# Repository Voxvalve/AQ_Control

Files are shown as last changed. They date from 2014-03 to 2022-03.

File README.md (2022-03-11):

==========
AQ_Control
==========

AQ_Control is an Arduino aquarium control system.

THE STORY:
--------------------------
It all started with me wanting something better then just a thermometer in each end og my 100cm long aquarium.
When i figured out how easy that was to do with an arduino i thought why not do more. 
also at this point there was alot of empty port on the Arduino UNO.
Then i figured that i might aswell do the light control with also.
After a while playing around with the date time stuff and having to set the time every time i flashed 
i went on amazon and ordered a DS1307 RCT to solve it(It works great!).
now i have all that sorted and i am currently testing the system.
So far everything seems to be working, Tempratures are read and displayed with great precision,
And lights are turned on/off at the specified time.

PARTS I USED:
--------------------------
1 x Arduino UNO.

2 x DS18B20.

1 x DS1307 RCT.

1 x 4-CH Relay Module.

Alot of pins and headers.

Some flat cable.

Some PCB.

Ferric chloride.

Laser printer with photo paper.

An iron.

Soldering iron

FEATURES FOR LATER
--------------------------
 - Web service for monitoring.
 - Email alert system.
 - Dynamic temprature control.
 - Automatic feeding system.

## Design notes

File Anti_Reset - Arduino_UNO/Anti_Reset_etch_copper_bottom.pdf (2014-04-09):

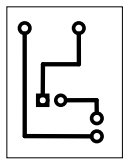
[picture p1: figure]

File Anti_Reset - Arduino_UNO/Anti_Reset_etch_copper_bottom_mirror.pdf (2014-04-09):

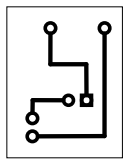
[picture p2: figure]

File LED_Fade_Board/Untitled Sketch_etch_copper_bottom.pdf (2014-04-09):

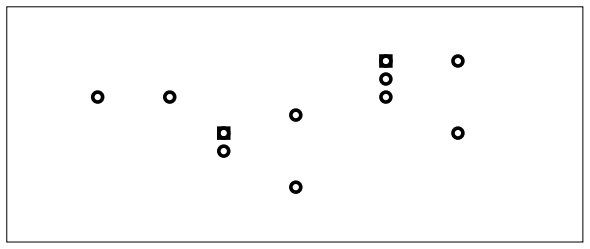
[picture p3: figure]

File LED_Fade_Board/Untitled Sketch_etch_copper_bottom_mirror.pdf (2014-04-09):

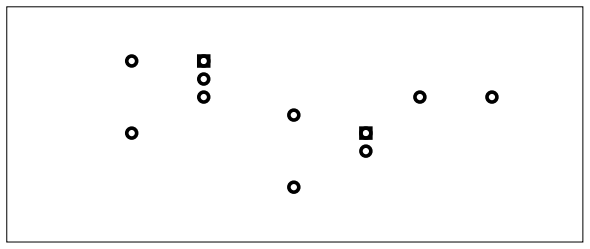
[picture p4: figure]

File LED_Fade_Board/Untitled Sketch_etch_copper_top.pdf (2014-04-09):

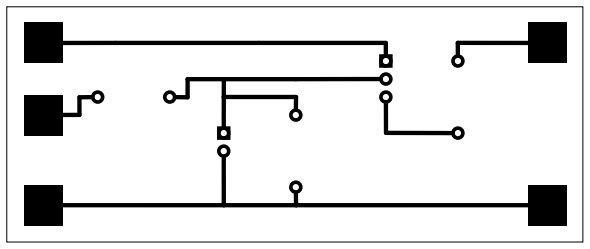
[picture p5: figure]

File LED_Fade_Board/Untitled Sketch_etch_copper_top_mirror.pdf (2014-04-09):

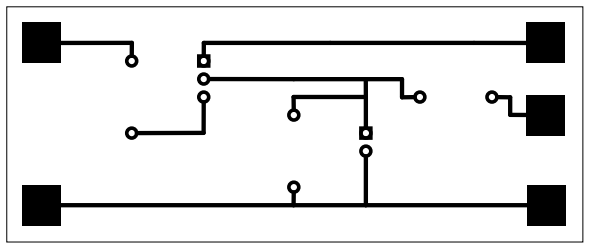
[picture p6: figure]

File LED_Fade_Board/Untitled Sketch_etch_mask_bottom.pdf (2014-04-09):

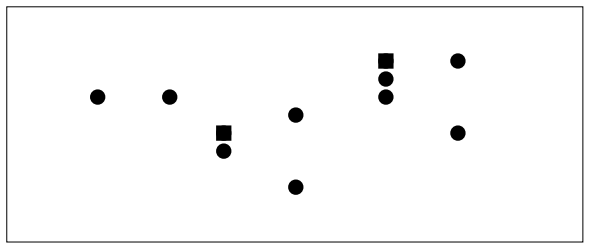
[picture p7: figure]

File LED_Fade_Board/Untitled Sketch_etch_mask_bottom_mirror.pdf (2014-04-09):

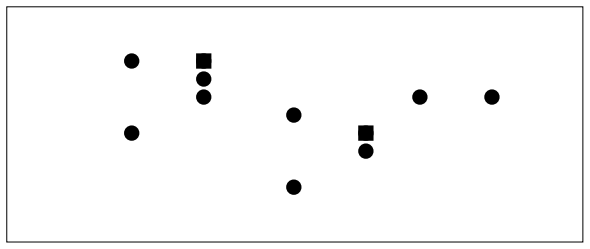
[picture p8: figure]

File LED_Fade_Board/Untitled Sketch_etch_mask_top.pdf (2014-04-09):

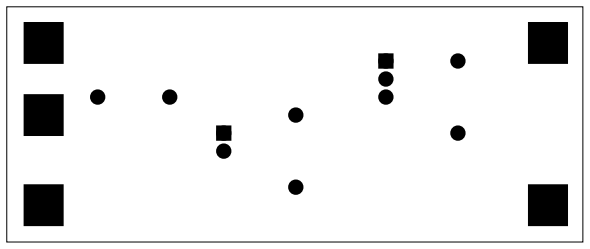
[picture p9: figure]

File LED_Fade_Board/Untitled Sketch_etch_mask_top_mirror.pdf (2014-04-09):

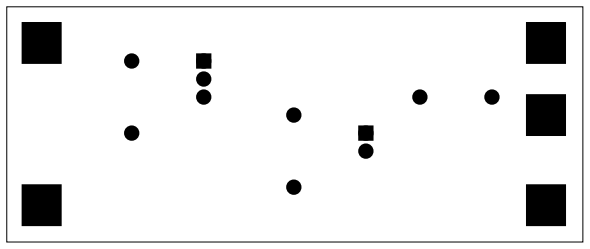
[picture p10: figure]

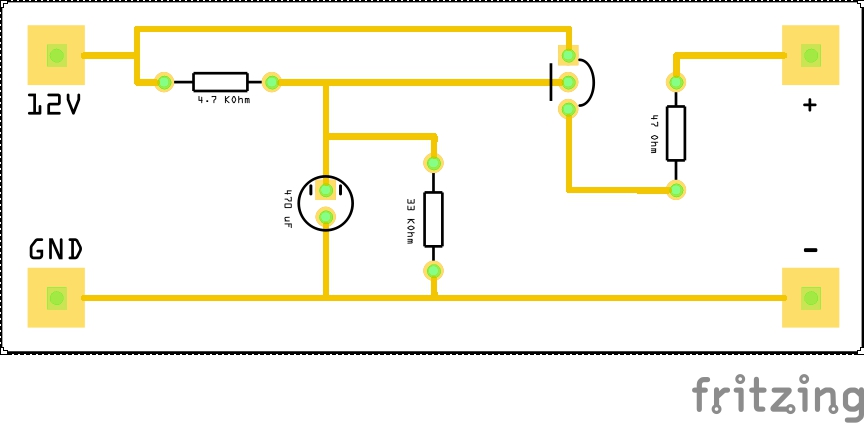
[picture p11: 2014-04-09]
LED_Fade_Board.jpg

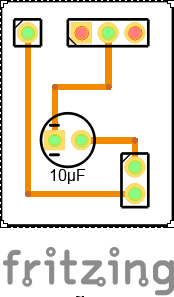
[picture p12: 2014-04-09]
Anti_Reset - Arduino_UNO/Anti_Reset_pcb.png

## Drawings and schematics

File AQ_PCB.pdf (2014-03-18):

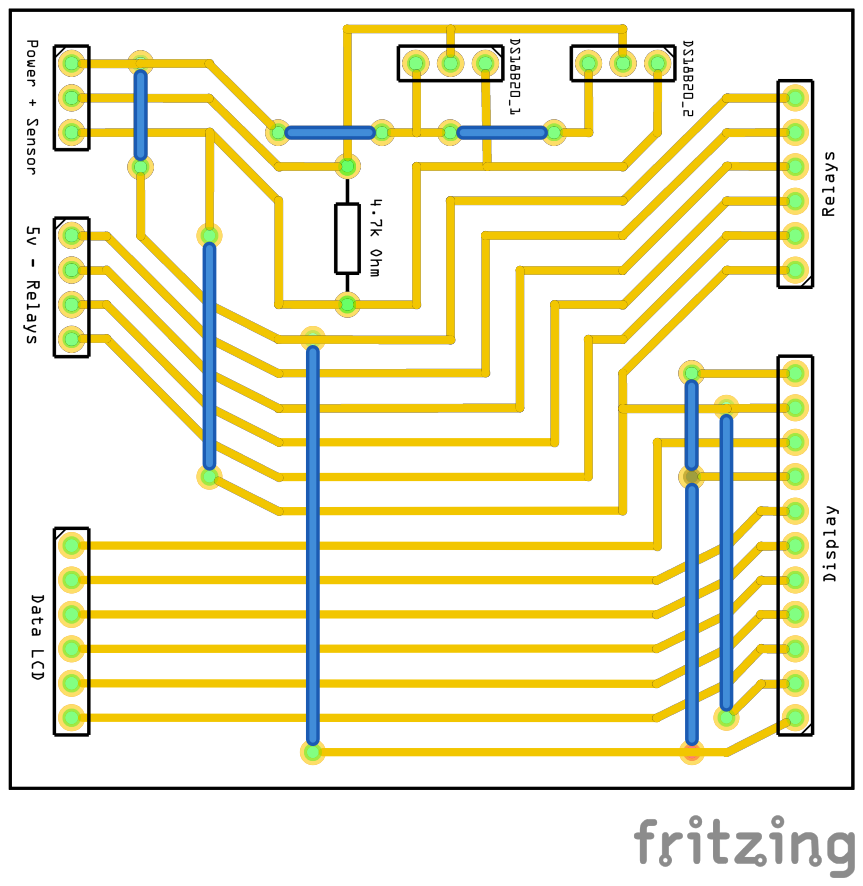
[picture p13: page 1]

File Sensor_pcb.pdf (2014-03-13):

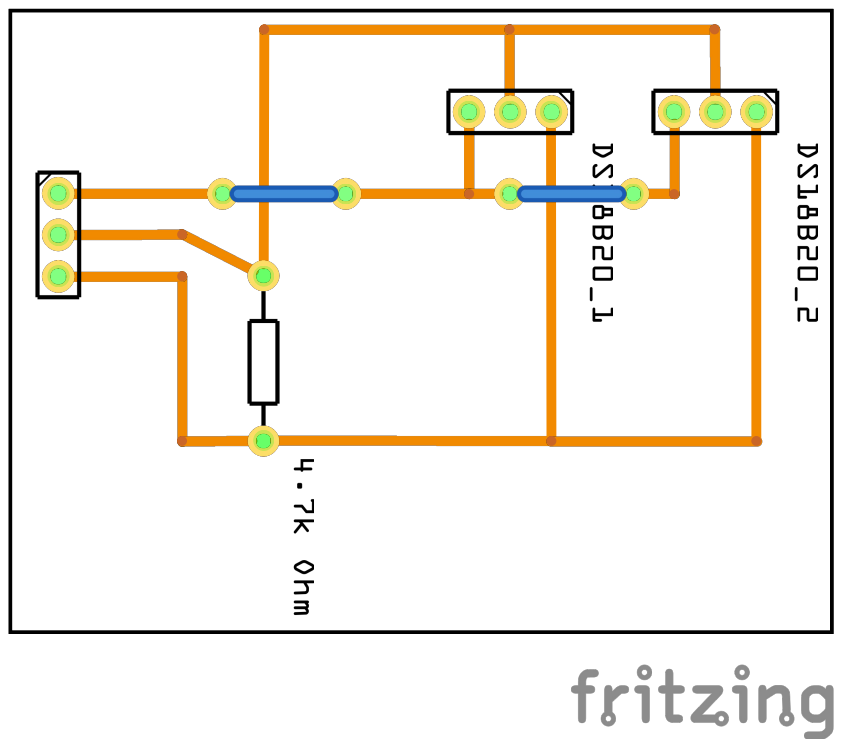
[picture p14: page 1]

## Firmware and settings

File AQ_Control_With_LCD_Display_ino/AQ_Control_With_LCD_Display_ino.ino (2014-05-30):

/*! \Cammand Lists
*      Commands that can used from a serial connection for testing functions.
*
*   1.) Print temprature.
*   2.) Turn on light.
*   3.) Turn off light.
*   4.) Lights Automatic.
*   5.) Print time from RTC.
*/
  
#define DS18S20_ID 0x10
#define DS18B20_ID 0x28
#define DS1307_ADDRESS 0x68
#define ONE_WIRE_BUS_PIN 14
#define RELAY1 8
#define RELAY2 9
#define RELAY3 10
#define RELAY4 11
#include <Wire.h>
#include <OneWire.h>
#include <DallasTemperature.h>
#include <LiquidCrystal.h>


// -- Variables to hold RTC --
int second;                                     
int minute;                                     
int hour;                                       
int weekDay;                                    
int monthDay;                                   
int month;                                      
int year;                                       
// ---------------------------

int intRead;                                    // int to identify command chosen.
int light = 0;                                  // State of lights (0 = Off, 1 = On & 2 = Manual.).
int offTime = 22;                               // Hour of the day to turn off lights.
int onTime = 10;                                // Hour of the day to turn on lights.
float temp;                                     // Holds temprature value of current read.
float temp1;                                    // Holds temprature of sensor1.
float temp2;                                    // Holds temprature of sensor2.
byte zero = 0x00;                               // Workaround for issue #527 in RTC.
LiquidCrystal lcd(2, 3, 4, 5, 6, 7);            // Initialize the library with the numbers of the interface pins.
OneWire oneWire(ONE_WIRE_BUS_PIN);
DallasTemperature sensors(&oneWire);

// Temprature sensor's addresses.
DeviceAddress Probe01 = { 0x28, 0x60, 0xB3, 0xA0, 0x05, 0x00, 0x00, 0x40 }; 
DeviceAddress Probe02 = { 0x28, 0xAD, 0x7A, 0xA0, 0x05, 0x00, 0x00, 0x44 };

/*! \Function to convert time.
*      bcdToDec();
*
*   Convert binary coded decimal 
*   to normal decimal numbers.
*/
byte bcdToDec(byte val)  {

  return ( (val/16*10) + (val%16) );
}

/*! \Function to get time.
*      getDate();
*
*   This gets the time from the DS1307
*/
void getDate() {
  // Reset the register pointer
  Wire.beginTransmission(DS1307_ADDRESS);
  Wire.write(zero);
  Wire.endTransmission();

  Wire.requestFrom(DS1307_ADDRESS, 7);

  second = bcdToDec(Wire.read());
  minute = bcdToDec(Wire.read());
  hour = bcdToDec(Wire.read() & 0b111111);       //24 hour time
  weekDay = bcdToDec(Wire.read());               //0-6 -> sunday - Saturday
  monthDay = bcdToDec(Wire.read());
  month = bcdToDec(Wire.read());
  year = bcdToDec(Wire.read());
}

/*! \Function to print time.
*      printDate();
*
*   Print the date EG 23:59:59
*/
void printDate(){
  
  Serial.print(hour);
  Serial.print(":");
  Serial.print(minute);
  Serial.print(":");
  Serial.println(second);
}

/*! \Function to get temperature.
*      printTemperature();
*
*   This gets the tempreature from
*   the DS18B20's Connected to pin 14
*   and converts it to degrees celsius.
*/
void printTemperature(DeviceAddress deviceAddress) {

   float tempC = sensors.getTempC(deviceAddress);

   if (tempC == -127.00) 
   {
     Serial.print("Error getting temperature  ");
   }
   else
   {
     temp = tempC;
   }
}

/*! \Control Lights ON.
*      lightsON();
*
*   This function will control the lights.
*   it will serve as the way for the timer
*   to turn the lights on at a 
*   specific time of the day.
*/
void lightsOn() {
  digitalWrite(RELAY4,LOW);                     // Turn on light 4.
  delay(5000);                                  
  digitalWrite(RELAY3,LOW);                     // Turn on light 3.
  delay(5000);                                  
  digitalWrite(RELAY2,LOW);                     // Turn on light 2
  delay(5000);                                  
  digitalWrite(RELAY1,LOW);                     // Turn on light 1.
  delay(3000);
  digitalWrite(RELAY2,HIGH);                    // Turn on light 4.
  delay(5000);                                  
  digitalWrite(RELAY3,HIGH);                    // Turn on light 3.
  delay(5000);                                  
  digitalWrite(RELAY4,HIGH);  
  light = 1;
}

/*! \Control Lights Off.
*      lightsOff();
*
*   This function will control the lights.
*   it will serve as the way for the timer
*   to turn the lights off at a 
*   specific time of the day.
*/
void lightsOff() {
  digitalWrite(RELAY4,LOW);                     // Turn on light 4.
  delay(5000);                                  
  digitalWrite(RELAY3,LOW);                     // Turn on light 3.
  delay(5000);                                  
  digitalWrite(RELAY2,LOW);                     // Turn on light 2
  digitalWrite(RELAY1,HIGH);                    // Turn off light 1.
  delay(5000);                                  
  digitalWrite(RELAY2,HIGH);                    // Turn off light 2.
  delay(5000);                                  
  digitalWrite(RELAY3,HIGH);                    // Turn off light 3.
  delay(5000);                                  
  digitalWrite(RELAY4,HIGH);                    // Turn off light 4.
  light = 0;
}

/*! \Write to LCD temp.
*      tempLCD();
*
*   Writes temprature to display
*/
void tempLCD() {
  sensors.requestTemperatures();
  delay(10);
  printTemperature(Probe01);                    // Get temprature from sensor1.
  temp1 = temp;
  delay(10);                                    // Wait for stability.
  printTemperature(Probe02);                    // Get temprature from sensor2.
  temp2 = temp;
  delay(10);                                    // Wait for stability.
  
  lcd.setCursor(0, 1);                          
  delay(10);
  lcd.print(temp1);                             // Write temprature from sensor1 to LCD.
  delay(10);
  lcd.setCursor(5, 1);                          
  delay(10);
  lcd.print("C");                               
  delay(10);
  lcd.setCursor(10, 1);                         
  delay(10);
  lcd.print(temp2);                             // Write temprature from sensor2 to LCD.
  delay(10);
  lcd.setCursor(15, 1);                         
  delay(10);
  lcd.print("C");
}

//-------- SETUP START --------//
void setup() {
  pinMode(RELAY1, OUTPUT);                      
  pinMode(RELAY2, OUTPUT);                      
  pinMode(RELAY3, OUTPUT);                      
  pinMode(RELAY4, OUTPUT);                      
  Serial.begin(9600);                           // Enable serial communication.
  lcd.begin(16, 2);                             // LCD number of colums and rows.
  Wire.begin();                                 // Start the connection to the RTC.
  lightsOn();                                   // Turn lights on by default.
  delay(5);                                     // Pause for stability.
  sensors.setResolution(Probe01, 10);
  sensors.setResolution(Probe02, 10);
}
//--------- SETUP END ---------//

//-------- LOOP START--------//
void loop() {
  
  tempLCD();
  delay(10);
  getDate();
  delay(10);
  
  //---- Light controlled by time ----//
  if(hour >= offTime || hour < onTime) {
    if (light == 1)
    {
      lightsOff();                              // Run function to turn off lights.
      delay(10);                                // Pause for stability.
    }
  }
  else if (hour >= onTime && hour < offTime) {
    if (light == 0)
    {
      lightsOn();                               // Run function to turn off lights.
      delay(10);                                // Pause for stability.
    }
  }
  //-- End light controlled by time --//
  
  if (temp1 < 25.00 || temp2 < 25.00) {
    lcd.setCursor(0, 0);                        
    lcd.print("WARNING TEMP LO ");              // Warning for low temprature.
  }
  else if (temp1 > 28.00 || temp2 > 28.00) {
    lcd.setCursor(0, 0);                        
    lcd.print("WARNING TEMP HI ");              // Warning for high temprature.
  }
  else {
    lcd.setCursor(0, 0);                        
    lcd.print("AQ-Control ");                   // Write standard text on screen.    
    
    // Making sure no number is left on display.
    if (hour < 10) {
      lcd.print("0");
      lcd.print(hour);
      lcd.print(":");
    }
    else {
      lcd.print(hour);
      lcd.print(":");
    }
    if (minute < 10) {
      lcd.print("0");
      lcd.print(minute);
    }
    else {
      lcd.print(minute);
    }
  }
  
  //-----------------------------
  //  Get command from serial
  //  and run the command listed.
  //-----------------------------
  // This will handle input from
  // the serial connection, and
  // run the functions requested
  // by the user/control unite.
  //-----------------------------
  //if (Serial.available()) {                     // read from serial.
  //  intRead = Serial.read();                    // Read the most recent int.    
  //  
  //  if (intRead == '1')                         // Command "1"from the command list.
  //  {      
  //    Serial.print(temp1);                      // Print temprature from sensor1 to serial.
  //    Serial.println("C");                      
  //    Serial.print(temp2);                      // Print temprature from sensor2 to serial.
  //    Serial.println("C");
  //    delay(5);                                 // Pause for stability.
  //  }
  //  else if (intRead == '2')                    // Command "2" from the command list.
  //  { 
  //    lightsOn();                               // Turn on lights.
  //    light = 2;
  //    delay(5);                                 // Pause for stability.
  //  }
  //  else if (intRead == '3')                    // Command "3" from the command list.
  //  { 
  //    lightsOff();                              // Turn off lights.
  //    light = 2;
  //    delay(5);                                 // Pause for stability.
  //  }
  //  else if (intRead == '4')                    // Command "3" from the command list.
  //  { 
  //    lightsOff();                              // Turn off lights.
  //    light = 0;
  //    delay(5);                                 // Pause for stability.
  //  }
  //  else if (intRead == '5')                    // Command "4" from the command list.
  //  { 
  //    printDate();                              // Print date time to console.
  //    delay(5);                                 // Pause for stability.
  //  }
  //}  
}
//--------- LOOP END ---------//

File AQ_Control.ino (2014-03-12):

/*-----------------------
       Cammand List
  -----------------------
  1.) Get temprature.
  2.) Turn on light.
  -----------------------
  0.) Get sensor address.
  -----------------------
*/
#define DS18S20_ID 0x10
#define DS18B20_ID 0x28
#define RELAY1 6
#define RELAY2 7
#define LED 13
#include <OneWire.h>

int intRead; // int to identify command chosen.
int pin_number = 2;
float temp; // Temprature of the water.
byte i;
byte present = 0;
byte data[12]; // This will hold the data returned by sensor.
byte addr[8]; // This will hold the address of the sensor.
boolean light = 0; // lights off by default.
OneWire ds(pin_number); // Select pin wher DS18B22 is connected.

//----------------------------------
//    Function to get temperature.
//----------------------------------
// This gets the tempreature from
// the DS18B20 Connected to pin 2
// and converts it to degrees celsius.
//----------------------------------
boolean getTemp(){
 
  temp = 00.00; // Debug purpose.
  
  // If device not found on addr return false.
  if (!ds.search(addr)) {
    ds.reset_search(); // Clear search state.
    //return false;
  }
  
  if (OneWire::crc8( addr, 7) != addr[7]) {
    return false;
  }
  
  if (addr[0] != DS18B20_ID) {
    return false;
  }
  
  ds.reset(); // Reset cycle to see if device still present.
  ds.select(addr); // Select rom after reset.
  
  ds.write(0x44, 1); // Start conversion
  
  delay(50); // Wait some time.
  present = ds.reset(); // Check if DS18B22 is present.
  ds.select(addr); // Select rom command addr 8.
  
  ds.write(0xBE); // Issue Read scratchpad command
   
  // Receive 9 bytes
  for ( i = 0; i < 9; i++) {
    data[i] = ds.read();
  }
  
  temp = ( (data[1] << 8) + data[0] )*0.0625; // Calculate temperature value
  return true;
}

//------------------------------------
//     Control Lights ON/OFF.
//------------------------------------
//This function will control the lights.
//it will serve as the way for the timer
//to turn the lights on and off at a 
//specific time of the day.
//------------------------------------
void lights() {
  if (light == 0) {
    digitalWrite(RELAY1,HIGH); // Turn on light 1.
    delay(2500); // Wait for a while.
    digitalWrite(RELAY2,HIGH); // Turn on light 2.
    light = 1; // Set light variable to on.
    digitalWrite(LED,HIGH); // Turn on LED to indicate lights on.
  }
  else if (light == 1) {
    digitalWrite(RELAY2,LOW); // Turn off light 2.
    delay(3000); // Wait for a while before turning on 2nd light.
    digitalWrite(RELAY1,LOW); // Turn off light 1.
    light = 0; // Set light variable to off.
    digitalWrite(LED,LOW); // Turn off LED to indicate lights off.
  }
}

//------------------------------------
//       Get sensor address.
//------------------------------------
//This function will assemble the
//address of the sensor and print in
//hexidecimal.
//------------------------------------
void getAddr() {
  for( i=0; i < 8; i++) {
      Serial.print("0x");
      if (addr[i] < 16) {
        Serial.print('0'); // Add a leading '0' if required.
      }
      Serial.print(addr[i], HEX); // print the actual value in HEX
      if (i < 7) {
        Serial.print(", "); // Print comma between the values.
      }
    }
  Serial.print("\r\n"); // New line after print.
}

//-------- SETUP START --------//
void setup() {
  pinMode(RELAY1, OUTPUT); // Set RELAY1(pin 6) to output.
  pinMode(RELAY2, OUTPUT); // Set RELAY2(pin 7) to output.
  pinMode(LED, OUTPUT); // Set onboard led to output.
  digitalWrite(RELAY1,LOW); // Turn off light 1 by default.
  digitalWrite(RELAY2,LOW); // Turn off light 2 by default.
  digitalWrite(LED,LOW); // turn off onboard led to indicate lights off.
  Serial.begin(9600); // Enable serial communication.
}
//--------- SETUP END ---------//

//-------- LOOP START--------//
void loop() {
  //-----------------------------
  //  Get command from serial
  //  and run the command listed.
  //-----------------------------
  // This will handle input from
  // the serial connection, and
  // run the functions requested
  // by the user/control unite.
  //-----------------------------
  if (Serial.available()) { // read from serial.
    intRead = Serial.read(); // Read the most recent int.    
    
    if (intRead == '1') // Command "1"from the command list.
    {      
      getTemp(); // Run function to get temprature.
      delay(5); // Pause for stability.
      Serial.print(temp); // Print temprature to serial.
      Serial.println("C");
    }
    else if (intRead == '2') // Command "2" from the command list.
    { 
      lights(); // Run function to control lights.
      delay(5); // Pause for stability.
    }
    else if (intRead == '0') // Command "2" from the command list.
    { 
      getAddr(); // Run function to control lights.
      delay(5); // Pause for stability.
    }
  }
}
//--------- LOOP END ---------//

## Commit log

2014-03-12 LOTS OF CHANGES AND ADDITIONS!
    - Aded command to read sensor address.
    - Fixes commants.
    - Added debug value to temprature readings.
    [AQ_Control.ino]
2014-03-12 Added Control
    - Added control for relays on pin 6 & 7.
2014-03-12 added comments and temporary fix return false.
    [AQ_Control.ino]
2014-03-13 Newe Version added.
    - LCD version with realtime updates.
    - Connector board design for OneWire DS18B20.
    [AQ_Board.fzz]
2014-03-13 Fixed connector PCB design
    [AQ_Board.fzz]
2014-03-17 Added new PCB design with relay connections.
    [AQ_Board.fzz]
2014-03-18 Updated PCB Design for Display Connection
    - Added display donnector to PCB design.
    [AQ_Board.fzz]
2014-03-21 Fixes and repositioned outputs.
    - Updated Comments.
    - Moved some connections around for optimal wirering.
    - Tested and works on Funduino UNO
    [AQ_Board.fzz]
2014-03-23 Added and fixed stuff.
    - Fixed lights on/off issue.
    - There is now seperate functions for turnning light on and off.
    - Started making the python code for the control unit.
    [Controls.py]
2014-03-30 Added - PCB
    NEW! - PCB for LCD display (Clicks on display and gives control over
    contrast on screen)
    [LCD_Adapter.fzz]
2014-03-31 Added PCB
    NEW! - Board for LED indicator's of temprature(RED, YELLOW, GREEN).
    [Status_LED_Board.fzz]
2014-04-01 Added RTC support.
    Added - support for RTC (DS1307)
    Deleted - Empty PDF's generated by PCB software.
    [AQ_Board.fzz, LCD_Adapter.fzz, Status_LED_Board.fzz]
2014-04-05 NEW VERSION!
    Changed - Sonsor addresses are now hardcoded to resolve several issues.
    Added - 2dn sensor.
    Added - 2nd sensor temprature to LCD display.
    Remade - Tempreature readout function to make sure temprature readouts
    are not mixed in code by mistake.
    Changed - The temprature is now calculated by the DallasTemprature
    library for better precistion.
    [AQ_Control_With_LCD_Display_ino.ino]
2014-04-07 Cleaned code and removed code that is no longer in use.
    [AQ_Control_With_LCD_Display_ino.ino]
2014-04-07 Fixed - Value for high temprature
    [AQ_Control_With_LCD_Display_ino.ino]
2014-04-07 Fixed - More commenting corrected.
    [AQ_Control_With_LCD_Display_ino.ino]
2014-04-07 Fixed - Github sync issue
    [AQ_Control_With_LCD_Display_ino.ino]
2014-04-07 Fixed - Github hopefully fixed this time.
    [AQ_Control_With_LCD_Display_ino.ino]
2014-04-08 UPDATE!!!
    Removed - No longer needed variables.
    Fixed - Some comments has been adjusted.
    [AQ_Control_With_LCD_Display_ino.ino]
2014-04-09 NEW! - Board for fading LED lights ON/OFF
    [Anti_Reset.fzz, Untitled Sketch.fzz]
2014-04-13 NEW!
    Fix - Temprature warning issue
    Added - Light fade in/out PCB
    [AQ_Control_With_LCD_Display_ino.ino]
2014-04-19 Fixed - Scrambled text on display issue
    [AQ_Control_With_LCD_Display_ino.ino]
2014-05-04 UPDATE!
    Fix - Testing a temporary workaround for display issues.
    Fix - Sun up/down cycle for reduced light during day (Algee fix).
    [AQ_Control_With_LCD_Display_ino.ino]
2014-05-22 Cleaned up some of the code (NOT TESTED!)
    //---------------------------------------------------//
    // ATTENTION: THIS VERSION IS NOT YET TESTED //
    //---------------------------------------------------//
    Description:
    New theory on display corruption is that it is coursed by noise from active relays.
    The noise does not compromise functionality and everything else should work just fine.
    NEW - Print temperature is now a function.
    Removed - Allot of unnecessary delays(Read description.)
    [AQ_Control_With_LCD_Display_ino.ino]
2014-05-30 Minor temp fix
    Fix - High and Low temps adjusted.
    [AQ_Control_With_LCD_Display_ino.ino]
